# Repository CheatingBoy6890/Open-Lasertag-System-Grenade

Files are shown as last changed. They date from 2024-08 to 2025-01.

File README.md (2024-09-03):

<div align="center">
  
PCBWay
###### Partnering with PCBway.
</div>
<br/>

# Open-Lasertag-System



##  ⚠️Warning⚠️ while this code works it is still wip and could have some bugs
---


https://commons.wikimedia.org/w/index.php?curid=1668938

Warning: This project uses lasers. Be sure to **always** do your own testing by meassuring voltage and current and by looking in datasheets. I am **not** responsible for any injuries you encounter from using this project. Also make sure to wear proper eye-protection.

---

<h2>What is Open-Lasertag-System?</h2>
Open-Lasertag-System is our approach to a build Lasertag that can be played anywhere without the need of setting up repeaters or servers, whilst beeing pretty easy to build and extend to fit your needs. It works decentral using a WIFI mesh,so the range and fun extends the more players you have!

Currently the project consists of five parts:

1.  The Taggers are fully functional with features such as different firemodes and score synchronization
2.  The vests are functional and connect wirelessly with the corresponding tagger
3.  Targets : For those who don't want to shoot at each other can just shoot at these. The plan also ist to intergrate the further into the system for modes like capture the Flag
4.  Logger: Counts wich target have been hit by whom
5.  There's a Laser grenade WIP

---

<h2>What is this repository?</h2>

This is the repository for the grenades of the system. here you'll find all the neccessary files on how to build a grenade your self.

**The instructions on building can be found in the <a href="https://github.com/CheatingBoy6890/Open-Lasertag-System-Grenade/tree/main/Hardware">Hardware folder</a>**

**What you'll need:**

- A 3D-printer capable of printing 20cmx20cm
- Soldering iron
- An ESP 8266 wemos d1 mini
- A piece of LED strip 8 LEDs ws2812b
- At least slightly transparent filament
-  perf matrix board or PCB (comming soon)
- Cable
- Pin headers
- Crimp equipment and or breadboard cables
- Tsop 4838
- 1 IR LED
- 10kΩ resistor
- bc 637 transistor
- 1x Button
- Switch
- Resistor 25Ω
- Battery holder 3 AA batteries
- 4x 6mmx30mm metal rod or pipe

- Time

  ## Who are we?

  We are two German students. Since we are twins, we build and programm a lot of projects together. We create all of our projects in our free time. Feel free to mail any questions to cyberfox3801@proton.me .
  We want to motivate people to discover what is possible using 3D printing and microcontrollers. \
  The most productive worker of our small group is our cat Susi. 

Congratulations you made it to the end of this readme. If you want this to be longer consider buying us a coffe (https://www.paypal.com/donate/?hosted_button_id=2RZBTA5GMNH6S) so we can make all files longer and better
and don't forget to cuddle your cat!

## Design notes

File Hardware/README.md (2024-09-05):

<div align="center">
  
PCBWay
###### Partnering with PCBway.
</div>
<br/>

# Hardware
## General Information 

Warning: This project uses lasers. Be sure to **always** do your own testing by meassuring voltage and current and by looking in datasheets. I am **not** responsible for any injuries you encounter from using this project. Also make sure to wear proper eye-protection.

## Where to get the components
The components are mostly standard components. We recommend buying them in a local store if possible to support the remaining stores.

We recommend ordering the PCBs at PCBWay, because they offer fast delivery and good quality at a low cost.
If you don't have a 3D printer you can also order the parts at PCBWay.

-----

**The Grenade runs using 3 1,2V NiMh batteries! Don't use voltages greater than 5V in order to power it.**

----

  **We recommend not to use a laser diode for the grenade, since it can be dangerous. Use a normal IR LED instead.** 

## The code

To flash the program to your ESP8266 you need to have <a href="https://code.visualstudio.com/">Visual Studio Code</a> and the platformio extension installed. If you haven't you can follow this tutorial:
<a>https://randomnerdtutorials.com/vs-code-platformio-ide-esp32-esp8266-arduino/</a> To flash an ESP8266 from Windows you might need additional drivers, you'll find a tutorial on this here https://randomnerdtutorials.com/install-esp32-esp8266-usb-drivers-cp210x-windows/

## Building the Grenade

#### Perf matrix board
If you're using a perf matrix board, make sure to cut out a 6x6 cm square.

#### PCB
We created the pcb layout with <a href="https://www.kicad.org/">KiCad</a>. You can easily order really nice high-quality PCBs from our partner [PCBWay](www.pcbway.com) by using the PCBWay plugin in KiCAD following this [turorial](https://www.pcbway.com/blog/News/PCBWay_Plug_In_for_KiCad_3ea6219c.html), exporting the gerber files manually like explained [here](https://www.pcbway.com/blog/help_center/How_to_Generate_Gerber_and_Drill_Files_in_KiCad_7_0_ab0d12bb.html) or use the gerber files in the repository (possibly outdated or not-yet available).

 

----

1. Make sure you have got all the required parts
2. Solder pins to your ESP d1 mini   - Make sure that the ESP8266 board is facing the top.Solder_pins (check and cross from pixabay Bild von <a href="https://pixabay.com/de/users/janjf93-3084263/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">Jan</a> auf <a href="https://pixabay.com/de//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">Pixabay</a> Bild von <a href="https://pixabay.com/de/users/openclipart-vectors-30363/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">OpenClipart-Vectors</a> auf <a href="https://pixabay.com/de//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">Pixabay</a>
3. Flash the ESP
5. Solder the components to your perf board ore PBCPCB

6. Solder cables to your button
7. Drill a small hole in the grenade shell and glue in the button
8. Solder a switch in the red cable of the battery clip
9. Crimp sockets on your battery clip 
12. Crimp sockets to the cables of the LED strip
13. Crimp sockets to the cables of the button
14. Connect LED strip, button and power
15. Glue the PCB or matrix board in the shell
    

17. Cut 4 pieces of 6mm x 30mm metal rod or tube
18. Heat up the pieces with a lighter and press them half way into the holes in one half of the shell until
   

20. Close the shell
21. Screw on the battery cover
22. Cuddle your cat

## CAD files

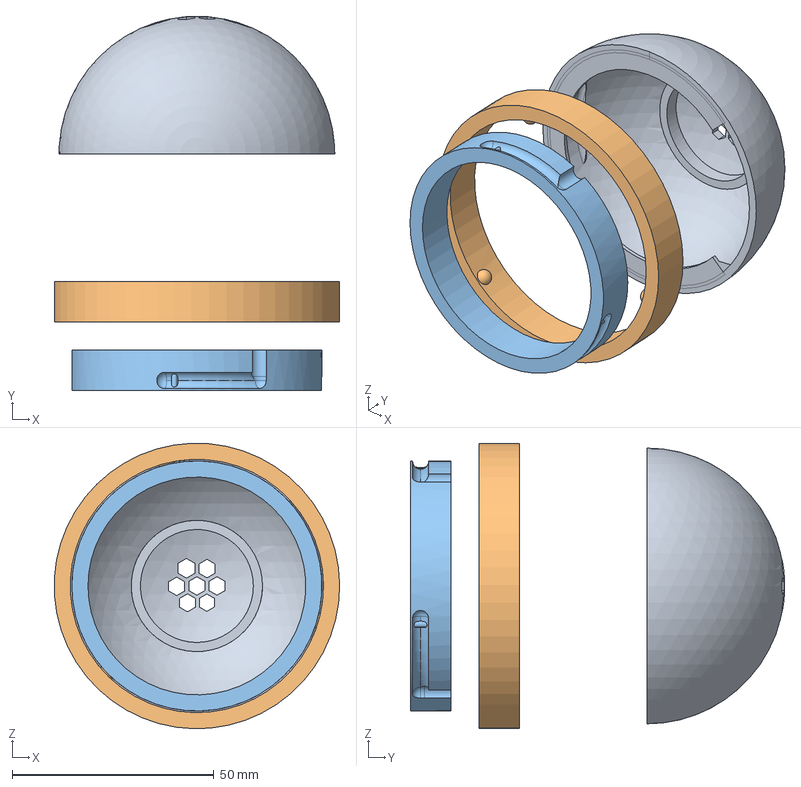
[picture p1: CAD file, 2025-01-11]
Hardware/3D_Print/Mini_Grenade.FCStd
70.7 x 92.7 x 70.8 mm
Battery_Half
Pin Part
Shaft Part

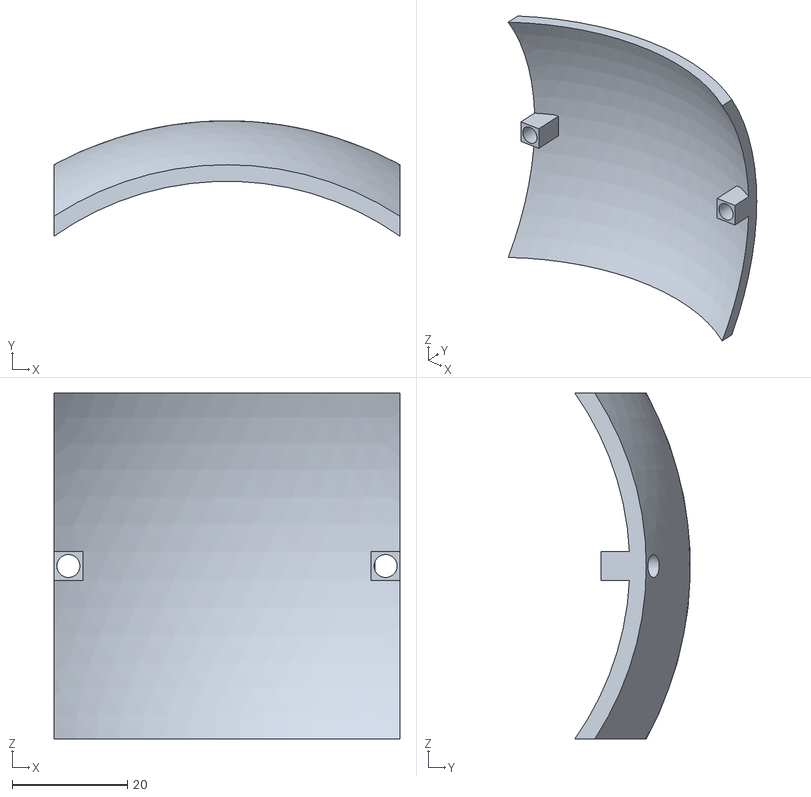
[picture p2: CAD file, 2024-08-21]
Hardware/BatteryCover.stl
60.0 x 20.0 x 60.0

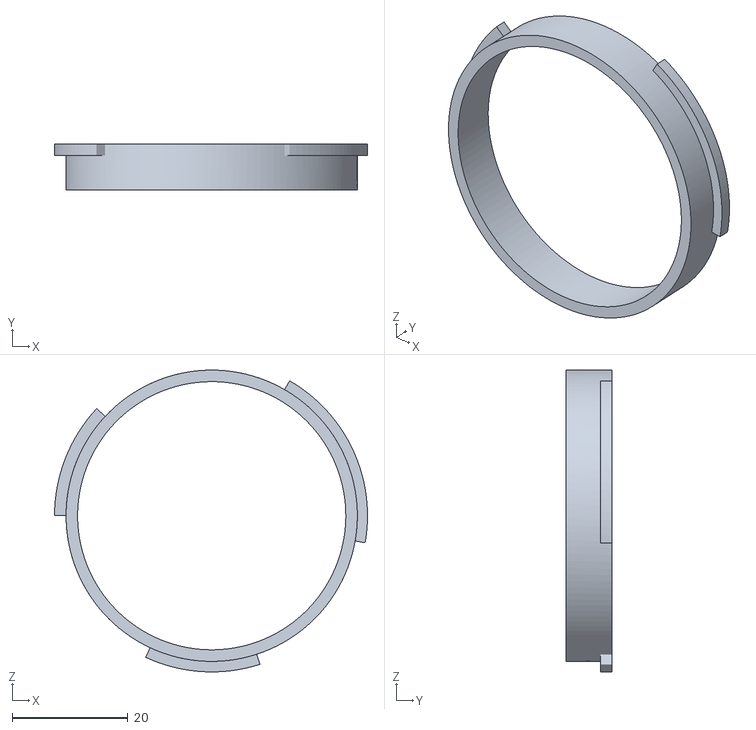
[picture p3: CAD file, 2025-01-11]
Hardware/3D_Print/Bajonette_2.stl
54.2 x 8.00 x 52.2

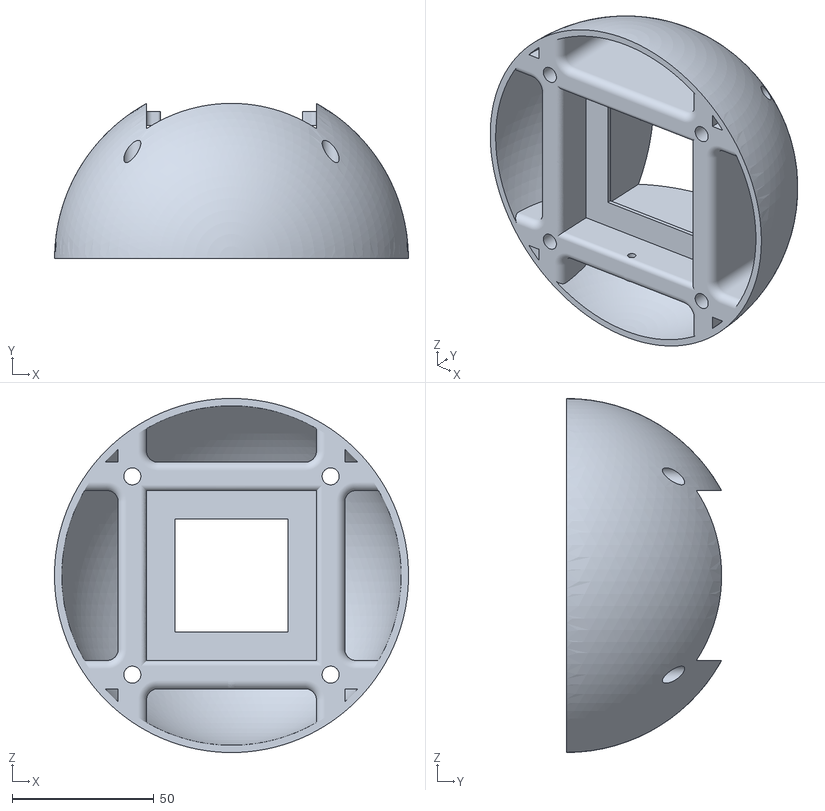
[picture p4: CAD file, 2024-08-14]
Hardware/LaserGrenadeP1.stl
125.0 x 54.8 x 125.0

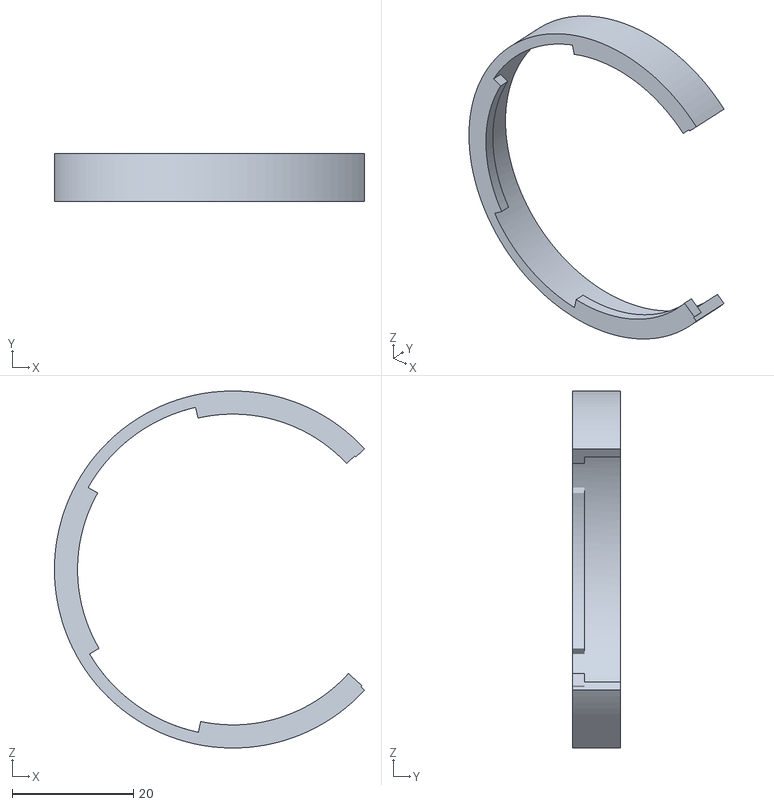
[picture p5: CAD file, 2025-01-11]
Hardware/3D_Print/Bajonette_1.stl
51.2 x 8.00 x 59.0

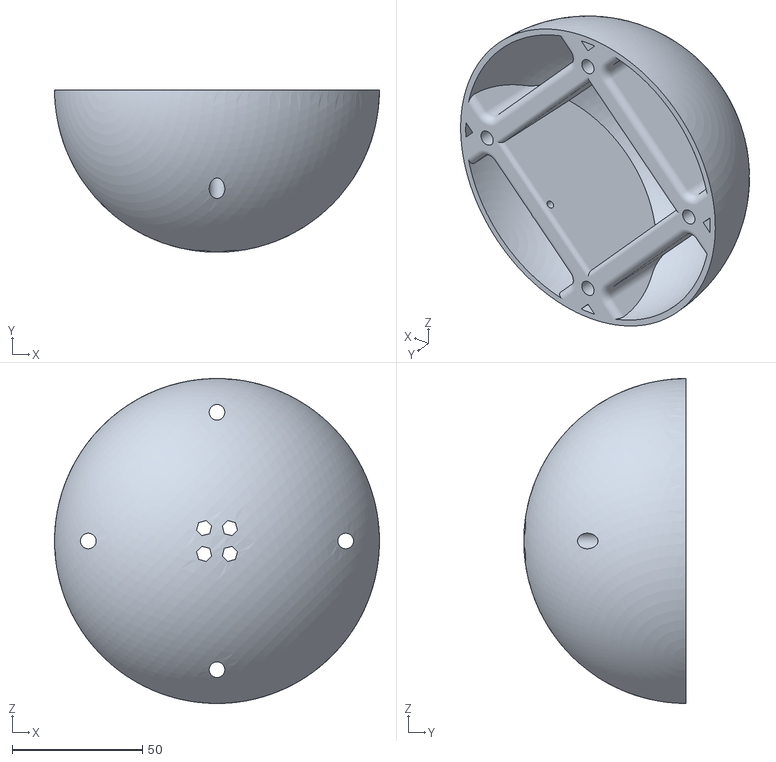
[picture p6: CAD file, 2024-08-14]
Hardware/LaserGrenadeP2.stl
125.0 x 62.5 x 125.0

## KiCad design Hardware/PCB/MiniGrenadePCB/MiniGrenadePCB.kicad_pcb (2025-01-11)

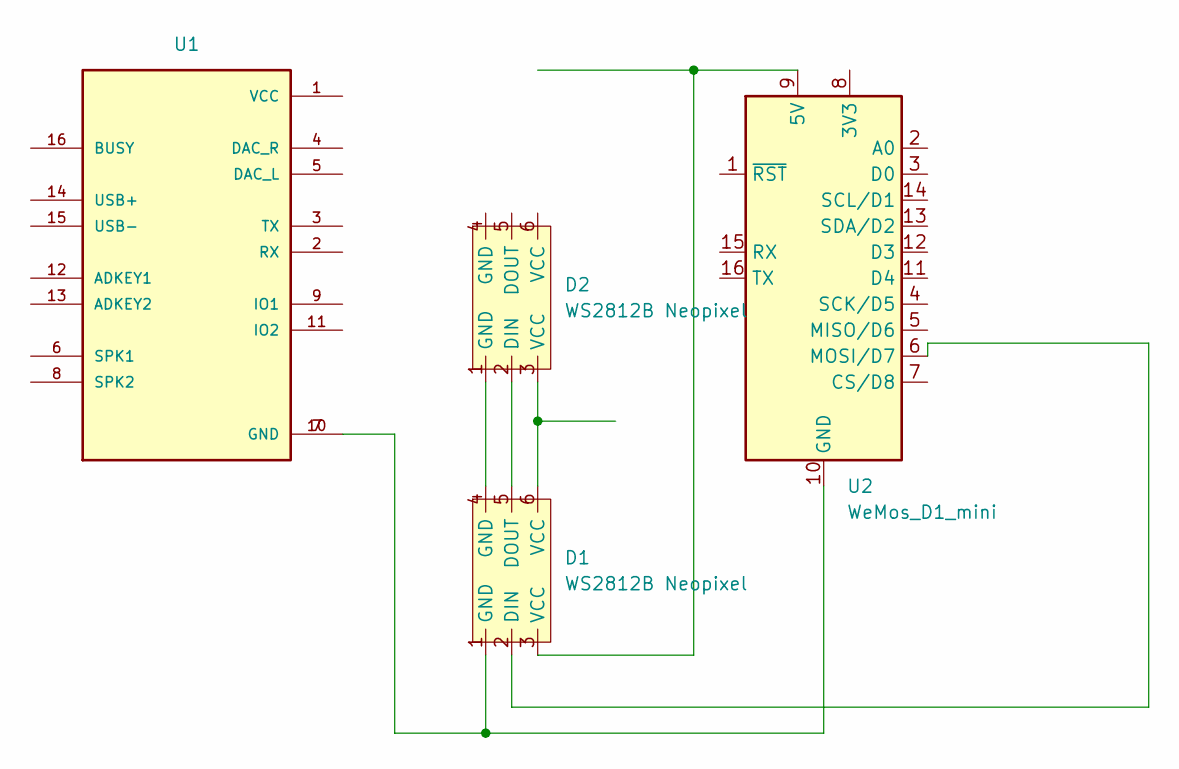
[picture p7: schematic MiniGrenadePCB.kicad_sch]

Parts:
D1, D2: WS2812B Neopixel; NeoPixel_strip
U1: DF-Player_mini
U2: WeMos_D1_mini; WEMOS_D1_mini_light

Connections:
unnamed: D1.2 (DIN), U2.6 (MOSI/D7)
unnamed: D1.5 (DOUT), D2.2 (DIN)
unnamed: D1.4 (GND), D2.1 (GND)
unnamed: D1.6 (VCC), D2.3 (VCC)
unnamed: D1.3 (VCC), U2.9 (5V)
unnamed: D1.1 (GND), U1.7 (GND), U1.10 (GND), U2.10 (GND)

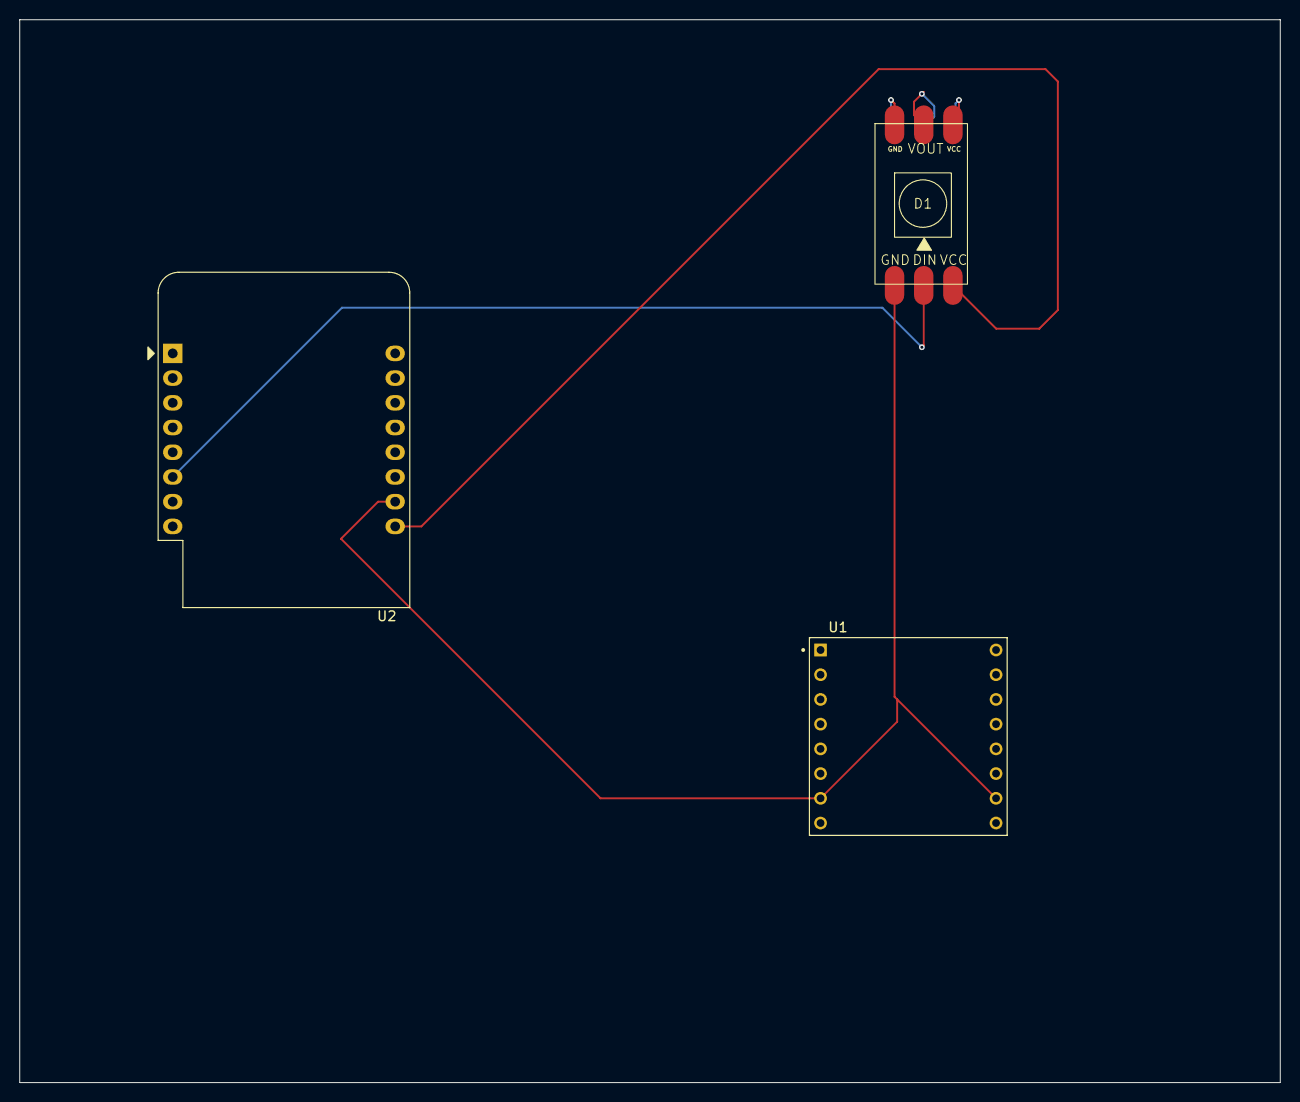
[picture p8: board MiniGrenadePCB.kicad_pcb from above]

Board: 2 copper layers, 129.5 x 109.2 mm, 4 parts (1 on the bottom side), 6 nets.

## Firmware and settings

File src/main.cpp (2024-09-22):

#include <Arduino.h>
#include <Adafruit_NeoPixel.h>
// #include <ESP8266Audio.h>
#include <AudioFileSourceLittleFS.h>
#include <AudioGeneratorWAV.h>
#include <AudioOutputI2SNoDAC.h>
#include <IRremoteESP8266.h>
#include <IRrecv.h>
#include <IRsend.h>

#define NUMLEDS 8
#define LEDPIN D2
#define RECEIVERPIN D1
#define Button D3
#define IRPIN D4
#define dammage 15

uint32_t teamColor[4]{
    0xff0000,
    0x0000ff,
    0xffff00,
    0x00ff00

};

uint8_t team;
uint8_t playerID;
decode_results results;

bool volatile goBooom = 0;
bool isConnected = 0;

float voltage;
Adafruit_NeoPixel pixels(NUMLEDS, LEDPIN, NEO_GRB + NEO_KHZ800);
IRrecv receiver(RECEIVERPIN);
IRsend transmitter(IRPIN);
AudioFileSourceLittleFS *file;
AudioGeneratorWAV *decoder;
AudioOutputI2SNoDAC *output;

// void IRAM_ATTR buttonInterrupt();
void booom();

void setup()
{
  Serial.begin(115200);
  Serial.println("Seial has bagun");
  pixels.begin();
  pixels.fill(0xffffff);
  pixels.show();
  receiver.enableIRIn();
  // attachInterrupt(digitalPinToInterrupt(Button), buttonInterrupt, FALLING);
  pinMode(Button, INPUT_PULLUP);
  pinMode(A0, INPUT);
  transmitter.begin();
  LittleFS.begin();
  file = new AudioFileSourceLittleFS("/explode.wav");
  decoder = new AudioGeneratorWAV();
  output = new AudioOutputI2SNoDAC();
  pinMode(D7, INPUT); // On the first version PCB the sound is connected to D7 which is useless since only RX can be the AudioOutput. Setting D7 as an Input prevents a short, since it should have a very high input resistans
  decoder->begin(file, output);
  decoder->SetBufferSize(512);
  output->SetGain(1);
  output->SetOutputModeMono(true);
}

void loop()
{
  voltage = analogRead(A0) * 0.005394;

  delay(100);
  Serial.println(digitalRead(Button));
  while (!isConnected)
  {
    Serial.println("Connection loop");
    if (receiver.decode(&results))
    {

      if (results.decode_type == MILESTAG2)
      {
        team = results.command >> 4;
        playerID = results.address;
        pixels.setBrightness(50);
        pixels.fill(teamColor[team]);
        pixels.show();
        Serial.print("set id and team to");
        Serial.print("Team:");
        Serial.println(team);
        Serial.printf("PlayerID:%i\n", playerID);
        isConnected = true;
      }
      receiver.resume();
    }
    delay(100);
  }
  booom();
}

/*void IRAM_ATTR buttonInterrupt()
{
  goBooom = 1;
} */
void booom()
{
  if (digitalRead(Button) == 0)
  {
    pixels.setBrightness(255);
    for (int i = 200; i > 0; i -= 10)
    {
      pixels.fill(teamColor[team]);
      pixels.show();
      delay(i);
      pixels.fill();
      pixels.show();
      delay(i);
    }
    pixels.fill(teamColor[team]);
    pixels.show();
    uint32_t data = 0;
    data = playerID;
    data = data << 2;
    data = data + team;
    data = data << 4;
    data = data + dammage;
    // transmitter.sendMilestag2(data);
    transmitter.sendMilestag2(data, 14, 0);
    decoder->stop();
    decoder->begin(file, output);
    decoder->loop();
    goBooom = 0;
    pixels.fill();
    pixels.show();
  }
  else if (voltage <= 2.8)
  {
    pixels.fill(0xff00ff);
    pixels.show();
  }
}

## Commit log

2024-08-14 Added the 3D files
    [LaserGrenadeP1.stl, LaserGrenadeP2.stl]
2024-08-21 Added the batter cover stl
    [BatteryCover.stl]
2024-09-03 Added the PCBWay Logo
2024-09-03 Added the PCB file
2024-09-14 added sound and fixed PCB
    [main.cpp]
2024-09-22 Fixed sound pin.
2024-10-19 Started adding Mini PCB, with custom footprints in the libraries folders, make sure to add them to KiCAD!
    [MiniGrenadePCB.kicad_pcb, MiniGrenadePCB.kicad_sch]
2024-10-19 Corrected PCB Oopsie+ began small grenade PCB
    [GrenadePCB.kicad_pcb, GrenadePCB.kicad_sch, MiniGrenadePCB.kicad_pcb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]
2025-01-11 Started working on the bayonet for the mini grenade
    [Bajonette_1.stl, Bajonette_2.stl, MiniGrenadePCB.kicad_pcb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]
2025-01-11 Added a bayonet from thingiverse (https://www.thingiverse.com/thing:6536797) to the MiniGrenade
    [Mini_Grenade.FCStd]
